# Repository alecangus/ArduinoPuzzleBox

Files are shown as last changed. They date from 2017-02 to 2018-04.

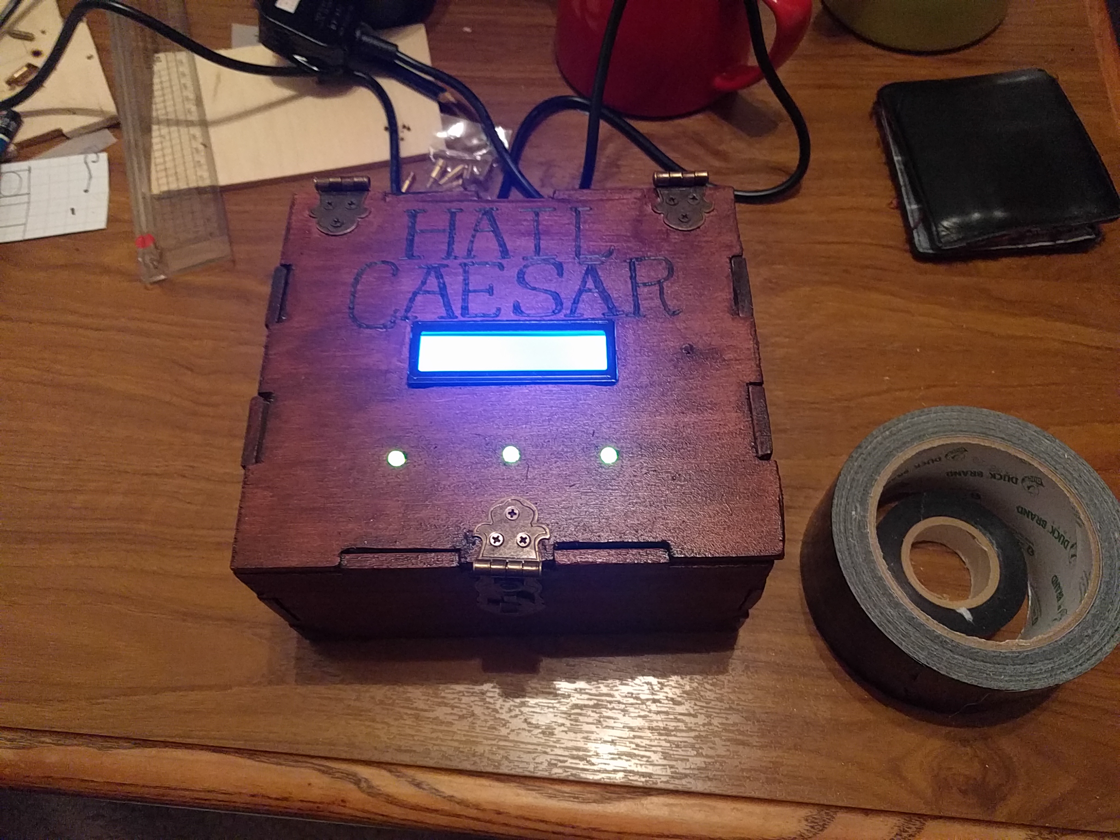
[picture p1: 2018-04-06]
images/DSC_0136.JPG

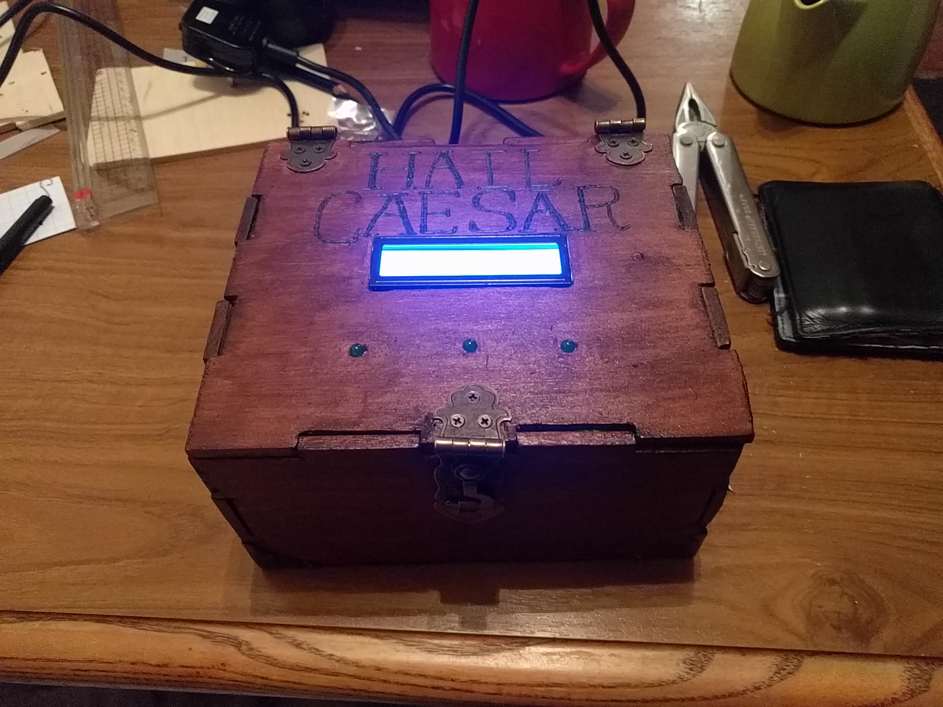
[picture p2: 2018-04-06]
images/DSC_0134.JPG

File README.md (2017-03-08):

# ArduinoPuzzleBox
A wooden haptics puzzle box based around a Caesar Cipher.
## Premise
Students are met with a wooden box with "Hail Caesar" burned into the lid. Also on the lid is an LCD panel reading "Knock on wood..." and three unlit LEDs. Knocking on the box causes the LCD screen output to change and all three LEDs to start blinking randomly. The box has transitioned into its next state.
### Lift me up high
Knocking on the box caused the box to pick a random number between 1 and 9, and use this as the key to a Caesar Cipher. The phrase "Lift me up high" is converted character by character into ASCII and shifted by this randomly selected key. This key remains constant throughout the rest of the game. The hope is that "Lift me up high" contains enough repeated characters, spaces and two-letter-words that the students will be able to recognise it as a ciphered text and be able to crack it. Cracking the cipher and lifting the box up >1m completes this level.
### Roll me over
The LCD readout changes again; applying the same key to the new cipher text produces "Roll me over". The first LED is now lit solid and the other two are switched off. Rolling the box such that it passes through being upside-down then the right way up again completes this level. A new cipher text is presented and the first two LEDs are now lit.
### Turn me round
Solving the new ciphertext with the same key produces the phrase "Turn me round". Flat-spinning the box 360 degrees completes this level. A new cipher text is presented and all three LEDs are now lit solid.
### Round of applause
The last level requests the students applaud themselves :p. Applause from more than one student will complete the game.
### Congratulations
In clear text the LCD scrolls the message "Congratulations! Passcode: We shall wear our glitter with pride"

## Ingredients
* Arduino Uno
* 2x16 LCD Screen
* Piezo
* Adafruit 10DOF IMU
* Battery
* 3xLEDs

## Technical notes
The loop of the Arduino is written to be a state machine where each of the states is listening to a different aspect of the box's haptic nature.
### State 0
A button on the back of the box switches the box on. The piezo is attached to the underside of the lid of the box and a slight hole is drilled. Initially the Arduino is listening to the piezo.
### State 1
The Arduino switches to using the Adafruit temperature and barometric pressure sensors to calculate its altitude. Smoothing is applied to these readings such that an average of the last 50 readings is used in each consideration to determine what height the box is at. This is to try to smooth away anomolous readings from the sensors.
### State 2
The Arduino then switches to smoothing readings from the Adafruit accelerometer and gyroscope to determine which way up it is. Once it's upside-down it waits to be the correct way up again.
### State 3
Using the Adafruit accelerometer, gyroscope and magnetic compass to determine that the box is staying the right way up and rotating through 360 degrees. I think it actually checks that it's rotated through at least 270 degrees or something like that...
### State 4
There's a threshold applied to the piezo readings to tune out background noise. The threshold we set in State 0 for the knocking is applied to a multiplier to try to get the Arduino to ignore one person clapping but recognise more than one person.

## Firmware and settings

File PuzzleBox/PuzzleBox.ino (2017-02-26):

#include <LiquidCrystal.h>
#include <Wire.h>
#include <Adafruit_Sensor.h>
#include <Adafruit_LSM303_U.h>
#include <Adafruit_BMP085_U.h>
#include <Adafruit_L3GD20_U.h>
#include <Adafruit_10DOF.h>

/*

  TODO:
    Calibrate the sensors?
    Get the ceasar cipher working
    Confirm team number

*/

// rs, rw, e, d0, d1, d2, d3, d4, d5, d6, d7
// LiquidCrystal lcd(4, 2, 3, 13, 12, 11, 10, 9, 8, 7, 6);
LiquidCrystal lcd(4, 2, 3, 9, 8, 7, 6);

Adafruit_LSM303_Accel_Unified accel = Adafruit_LSM303_Accel_Unified(30301);
Adafruit_BMP085_Unified       bmp   = Adafruit_BMP085_Unified(18001);
Adafruit_LSM303_Mag_Unified   mag   = Adafruit_LSM303_Mag_Unified(30302);

const int levelOneLED = 10;
const int levelTwoLED = 11;
const int levelThreeLED = 12;
const int stageZeroTimeout = 2000; // Number of milliseconds to wait for knocking to end
const int PIEZO = A0;

const float heightThreshold = 0.7; // Height the box has to travel upwards to complete level
const int knockThreshold = 100;     // threshold value to decide when a knock value is detected
const int clapThreshold = 50;       // Threshold value to decide when applause is detected
const float seaLevelPressure = SENSORS_PRESSURE_SEALEVELHPA;
const int smoothingCount = 50;

int state; // 0 = Team number, 1 = Liftmeup, 2 = Roll me over, 3 = spin me round, 4 = applause, 5 = eliza
unsigned long lastKnock = false;
int knockVal; // variable to store the value read from the piezo
float startHeight;
float startHeading;

// Smoothing
float heightSmoothing[smoothingCount];
int heightSmoothingIndex = 0;
float heightSmoothingTotal = 0.0;
float heightSmoothingAverage = 0.0;

float headingSmoothing[smoothingCount];
int headingSmoothingIndex = 0;
float headingSmoothingTotal = 0.0;
float headingSmoothingAverage = 0.0;

int teamNumber = 0;

void setup() {
  Serial.begin(9600);
  Serial.println("Starting setup");
  lcd.begin(16, 2);
  accel.begin();
  bmp.begin();
  mag.begin();

  // *************** Get smoothed start height ***************
  float temperature;
  bmp.getTemperature(&temperature);
  sensors_event_t event;
  for (int i = 0; i < smoothingCount; i++) {
    bmp.getTemperature(&temperature);
    bmp.getEvent(&event);
    heightSmoothing[i] = bmp.pressureToAltitude(seaLevelPressure,
                                          event.pressure,
                                          temperature);
    startHeight += heightSmoothing[i];
    heightSmoothingTotal += heightSmoothing[i];
  }
  startHeight = startHeight / smoothingCount;
  heightSmoothingAverage = heightSmoothingTotal / smoothingCount;
  // *************** End smoothed start height ***************
  
  pinMode(levelOneLED, OUTPUT);
  pinMode(levelTwoLED, OUTPUT);
  pinMode(levelThreeLED, OUTPUT);

  // Set up for State 0
  state = 0;
  Serial.println("Finished setup");
  randomSeed(analogRead(0));
  display("Knock on wood...", "                ");
}

void loop() {
  /* State zero, "Knock on wood"
   *  Lights are cycling or flashing randomly
   */
  if (state == 0) {
    // Light everything up
    //setLights(random(0,2), random(0,2), random(0,2));
    setLights(0, 0, 0);
    
    // ******************* Count the knocks *************************
    
    knockVal = analogRead(PIEZO); // read the sensor
    if (lastKnock && (lastKnock + stageZeroTimeout) < millis()) { // Knocking has begun and stopped
      Serial.print("Finished listening for knocks, Team Number = ");
      Serial.println(teamNumber);
      // Move to stage 1
      state = 1;
      display(encrypt("Hold me up high"), "                ");
    }
    else if (knockVal >= knockThreshold) { // If knock detected, handle
      lastKnock = millis();
      teamNumber++;
    setLights(1, 0, 0);
    delay(10);
    setLights(0, 1, 0);
    delay(10);
    setLights(0, 0, 1);
    delay(10);
    }
    //delay(30);
    teamNumber = random(1,10);
    // *********** End count the knocks **************
  }

  /* Lift Me Up */
  if (state == 1) {
    setLights(random(0,2), random(0,2), random(0,2));

    // ******************* Lift Me Up *************************
    heightSmoothingTotal -= heightSmoothing[heightSmoothingIndex];
    sensors_event_t event;
    bmp.getEvent(&event);
    float temperature;
    bmp.getTemperature(&temperature);
    heightSmoothing[heightSmoothingIndex] = bmp.pressureToAltitude(seaLevelPressure,
                                        event.pressure,
                                        temperature);
    heightSmoothingTotal += heightSmoothing[heightSmoothingIndex];
    heightSmoothingIndex++;
    if (heightSmoothingIndex >= smoothingCount) {
      heightSmoothingIndex = 0;
    }
    heightSmoothingAverage = heightSmoothingTotal / smoothingCount;
    if (heightSmoothingAverage - startHeight > heightThreshold) {
      Serial.println("Moving to stage 2");
      state = 2;
      display(encrypt("Roll me over"), ""); // 3 = Uroo#ph#ryhu
    } else {
      Serial.print("Stage 2: startHeight: ");
      Serial.print(startHeight);
      Serial.print(", heightSmoothingAverage: ");
      Serial.print(heightSmoothingAverage);
      Serial.print(". Total: ");
      Serial.println(heightSmoothingAverage - startHeight);
    }
    // ***************** End Lift Me Up ***********************
  }

  /* Roll me over */
  if (state == 2) {
    setLights(1, 0, 0);

    // ******************* Roll Me Over *************************
    sensors_event_t event;
    accel.getEvent(&event);
    
    if (event.acceleration.z > 10) { // Upside down


      delay(2000);


      
      accel.getEvent(&event);
      while (!(event.acceleration.z < -10)) {
        // Do nothing waiting for the box to return to the right way up
        accel.getEvent(&event);
      }



      
      startHeading = (atan2(event.magnetic.y,event.magnetic.x) * 180) / PI;
      if (startHeading < 0) {
        startHeading += 360;
      }
      Serial.println("Moving to stage 3");
      state = 3;
      display(encrypt("Turn Me Round"), ""); // 3 = Uroo#ph#ryhu
    }
    // ***************** End Roll Me Over ***********************
  }

  /* Spin me round */
  if (state == 3) {
    setLights(1, 1, 0);

    // ******************* Turn Me Round *************************
    sensors_event_t event;
    mag.getEvent(&event);
    accel.getEvent(&event);
    float currentHeading = (atan2(event.magnetic.y,event.magnetic.x) * 180) / PI;
    if (currentHeading < 0) {
      currentHeading += 360;
    }
    if (abs(startHeading - currentHeading) > 170 && (event.acceleration.z < -10)) { // The box is 180 degrees turned in a flat spin and the right way up
      Serial.println("Moving to state 4");
      state = 4;
      display(encrypt("Applaud"), "");
    }
    // ***************** End Turn Me Round ***********************
  }

  /* Applaude */
  if (state == 4) {
    setLights(1, 1, 1);
    
    // ******************* Applause *************************
    
    knockVal = analogRead(PIEZO); // read the sensor
    if (knockVal >= clapThreshold) { // I hear applause
      // Move to stage 5
      state = 5;
    }
    else { // Not loud enough
      if (knockVal > 0) {
        Serial.print("Clapping: [");
        Serial.print(knockVal);
        Serial.println("]");
      }
    }

    // *********** End Applause *******************************
  }

  if (state == 5) {
    scrollLongText("Congratulations! Passcode: We shall wear our glitter with pride ");
  }
}

void display (String line1, String line2) {
  lcd.clear();
  Serial.println("Displaying on 1: [" + line1 + "]");
  Serial.println("Displaying on 2: [" + line2 + "]");
  int padding = (16-line1.length())/2;
  lcd.setCursor(padding,0);
  lcd.print(line1);
  lcd.setCursor(0, 1);
  lcd.print(line2);

}

void setLights (bool one, bool two, bool three) {
  digitalWrite(levelOneLED, one);
  digitalWrite(levelTwoLED, two);
  digitalWrite(levelThreeLED, three);
}

String encrypt (String s) {
  int len = s.length();
  String encrypted = s;
  for (int i=0;i<len;i++) {
    if ((s[i] + teamNumber) <= 122) {
      encrypted[i] = s[i] + teamNumber;
    } else {
      encrypted[i] = (s[i] + teamNumber) - 90; // Wrap around 
    }
  }
  return encrypted;
}

void scrollLongText (String text) {
int stringStart, stringStop = 0;
int scrollCursor = 16;
  for (int i = 0; i < text.length(); i++) {
  lcd.setCursor(scrollCursor, 0);
  lcd.clear();
  lcd.print(text.substring(stringStart,stringStop));
  lcd.setCursor(0, 1);
  lcd.print("");
  delay(300);
  if(stringStart == 0 && scrollCursor > 0){
    scrollCursor--;
    stringStop++;
  } else if (stringStart == stringStop){
    stringStart = stringStop = 0;
    scrollCursor = 16;
  } else if (stringStop == text.length() && scrollCursor == 0) {
    stringStart++;
  } else {
    stringStart++;
    stringStop++;
  }
  }
  delay(5000);
}

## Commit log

2017-02-26 First go at a schematic
    [PuzzleBoxSchematic.fzz]
2017-02-26 Cleaned the wiring up a bit (yeah, it was actually worse than this...)
    [PuzzleBoxSchematic.fzz]
